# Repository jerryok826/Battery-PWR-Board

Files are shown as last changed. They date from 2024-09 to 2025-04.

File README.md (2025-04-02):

# Battery PWR Board

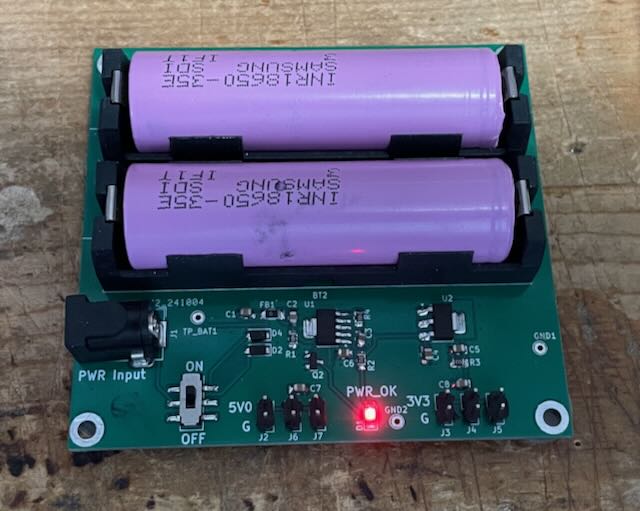
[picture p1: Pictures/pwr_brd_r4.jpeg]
Robot_Front


## Project Description
As systems and devices to test get smaller, large power supplies with their fans are often not required. The "Battery PWR Board" is a small board that can supply 5.0 amd/or 3.3 Volts. In a typical case two 18650 batteries may all that's required. The board can also run from a 9 volt battery or a wall wart. The on board PWR_OK LED is on when the 5.0 volt rail is within valid limits. Guaranting the batteries are ok. Since it can run from batteries and there is no active switching devices on board it is very low noise. 

### Project Status
The project is basically complete.

## Design Files
This project was designed with Kicad 7.X

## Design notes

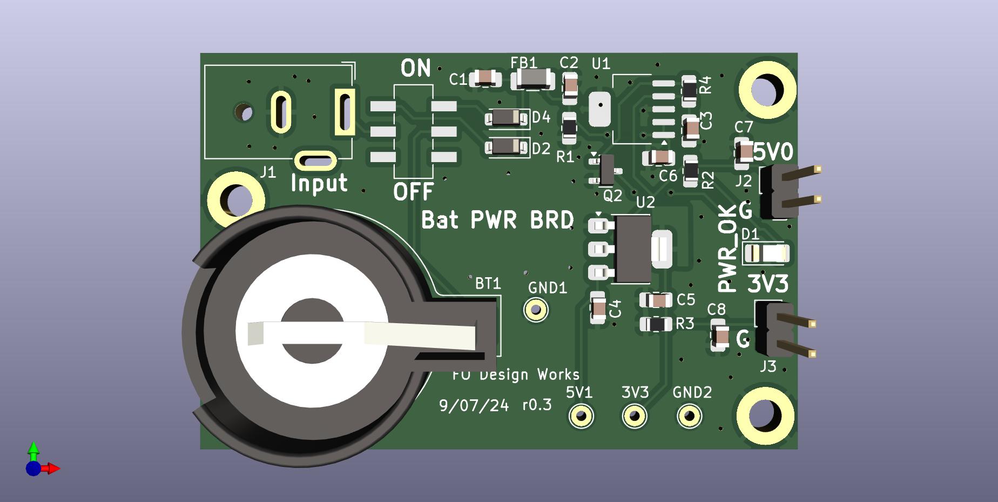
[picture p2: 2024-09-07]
Hardware/Kicad/battery_pwr_brd_r3.jpg

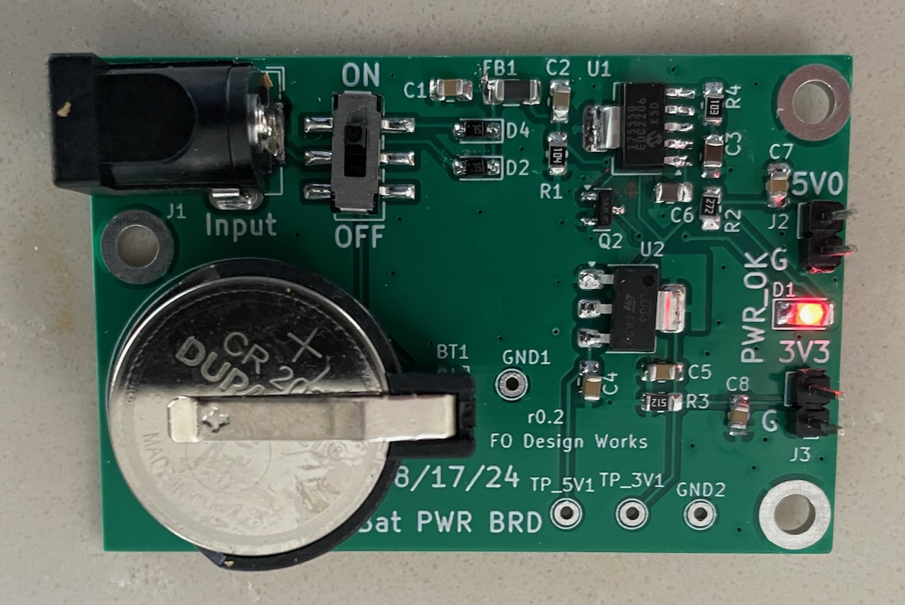
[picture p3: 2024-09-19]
Pictures/battery_pwr_brd_r3.jpeg

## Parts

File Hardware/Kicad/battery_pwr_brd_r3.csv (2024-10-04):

Source: | /home/jerryo/kicad/battery_pwr_brd/battery_pwr_brd_r3/battery_pwr_brd_r3.kicad_sch
Date: | Fri 04 Oct 2024 03:51:49 PM PDT
Tool: | Eeschema 7.0.11-7.0.11~ubuntu22.04.1
Generator: | /usr/share/kicad/plugins/bom_csv_grouped_by_value.py
Component Count: | 23
Collated Components:
Item | Qty | Reference(s) | Value | LibPart | Footprint | Datasheet | DNP | Description | Vendor | Vendor Part#
1 | 1 | BT1 | BATT HLD COIN 20MM 2 CELL PC PIN | Device:Battery | Battery:BatteryHolder_Keystone_103_1x20mm | ~ |  |  | Digikey | BH800S-ND
2 | 4 | C1, C2, C7, C8 | 0.1uF | Device:C_Small | Capacitor_SMD:C_0805_2012Metric_Pad1.18x1.45mm_HandSolder | ~ |  | CAP CER, 0.1uF, 25V, X7R, 0805 | Digikey | 1276-1099-1-ND
3 | 2 | C3, C6 | 4.7uF | Device:C_Small | Capacitor_SMD:C_0805_2012Metric_Pad1.18x1.45mm_HandSolder | ~ |  | CAP CER, 4.7uF, 25V, X7R, 0805 | Digikey | 1276-1244-1-ND
4 | 2 | C4, C5 | 1uF | Device:C_Small | Capacitor_SMD:C_0805_2012Metric_Pad1.18x1.45mm_HandSolder | ~ |  | CAP CER 1UF 25V X7R 0805 | Digikey | 1276-1066-1-ND
5 | 1 | D1 | PWR_OK | Device:LED | LED_SMD:LED_1206_3216Metric_Pad1.42x1.75mm_HandSolder | https://sunledusa.com/products/spec/XZM2CRK55W-3.pdf |  | LED RED CLEAR SMD 1206 | Digikey | 732-11422-1-ND
6 | 2 | D2, D4 | 1N5819W | Diode:1N5819WS | Diode_SMD:D_SOD-123 | https://datasheet.lcsc.com/lcsc/2204281430_Guangdong-Hottech-1N5819WS_C191023.pdf |  | DIODE SCHOTTKY 40V 1A SOD123FL | Digikey | 1655-1N5819WCT-ND
7 | 1 | FB1 | FerriteBead, 6A 1 9mΩ 33Ω@100MHz ±25% 1206 Ferrite Beads ROHS | Device:FerriteBead_Small | Inductor_SMD:L_1206_3216Metric_Pad1.42x1.75mm_HandSolder | https://www.fair-rite.com/wp-content/themes/fair-rite/print_product.php?pid=19229 |  | FERRITE BEAD 50 OHM 1206 1LN | Digikey | 1934-1465-1-ND
8 | 1 | J2 | Output_5V | Connector_Generic:Conn_01x02 |  | ~
9 | 1 | J3 | Output_3V3 | Connector_Generic:Conn_01x02 |  | ~
10 | 1 | Q2 | MMBT3904 | Transistor_BJT:MMBT3904 | Package_TO_SOT_SMD:SOT-23 | https://www.onsemi.com/pdf/datasheet/pzt3904-d.pdf |  | TRANS NPN 40V 0.2A SOT23-3 | Digikey | SMMBT3904LT3GOSCT-ND
11 | 1 | R1 | 100K | Device:R_Small_US | Resistor_SMD:R_0805_2012Metric_Pad1.20x1.40mm_HandSolder | ~ |  | RES 100K OHM %1 1/10W 0805 SMD | Digikey | 311-100KCRCT-ND
12 | 1 | R2 | 2.7K | Device:R_Small_US | Resistor_SMD:R_0805_2012Metric_Pad1.20x1.40mm_HandSolder | ~ |  | RES 2.7K OHM %1 1/10W 0805 SMD | Digiley | A126359CT-ND
13 | 1 | R3 | 5.1K | Device:R_Small_US | Resistor_SMD:R_0805_2012Metric_Pad1.20x1.40mm_HandSolder | ~ |  | RES 5.1K OHM %1 1/10W 0805 SMD | Digikey | 311-5.1KARCT-ND
14 | 1 | R4 | 10K | Device:R_Small_US | Resistor_SMD:R_0805_2012Metric_Pad1.20x1.40mm_HandSolder | ~ |  | RES 10K OHM %1 1/10W 1206 SMD | Digkey | 311-10.0KCRCT-ND
15 | 1 | SW1 | SW_DPDT_x2 | :SW_DPDT_x2_1 | jerrys_Library:SW_DPDT_CK_JS202011JCQN | https://www.ckswitches.com/media/1422/js.pdf |  | SWITCH SLIDE DPDT 300MA 6V | Digikey | 401-2002-1-ND
16 | 1 | U1 | MCP1755 | :MCP1755_1 | Package_TO_SOT_SMD:SOT-223-6 | https://ww1.microchip.com/downloads/en/DeviceDoc/MCP1755-MCP1755S-Data-Sheet-DS20005160B.pdf |  | IC REG LIN 3.3V 300MA SOT223-3 | Digikey | MCP1755ST-3302E/DBCT-ND
17 | 1 | U2 | LM1117MP-3.3 | Regulator_Linear:LM1117MP-3.3 | Package_TO_SOT_SMD:SOT-223-3_TabPin2 | http://www.ti.com/lit/ds/symlink/lm1117.pdf |  | IC REG LINEAR 3.3V 800MA SOT223 | Digikey | 497-1242-1-ND

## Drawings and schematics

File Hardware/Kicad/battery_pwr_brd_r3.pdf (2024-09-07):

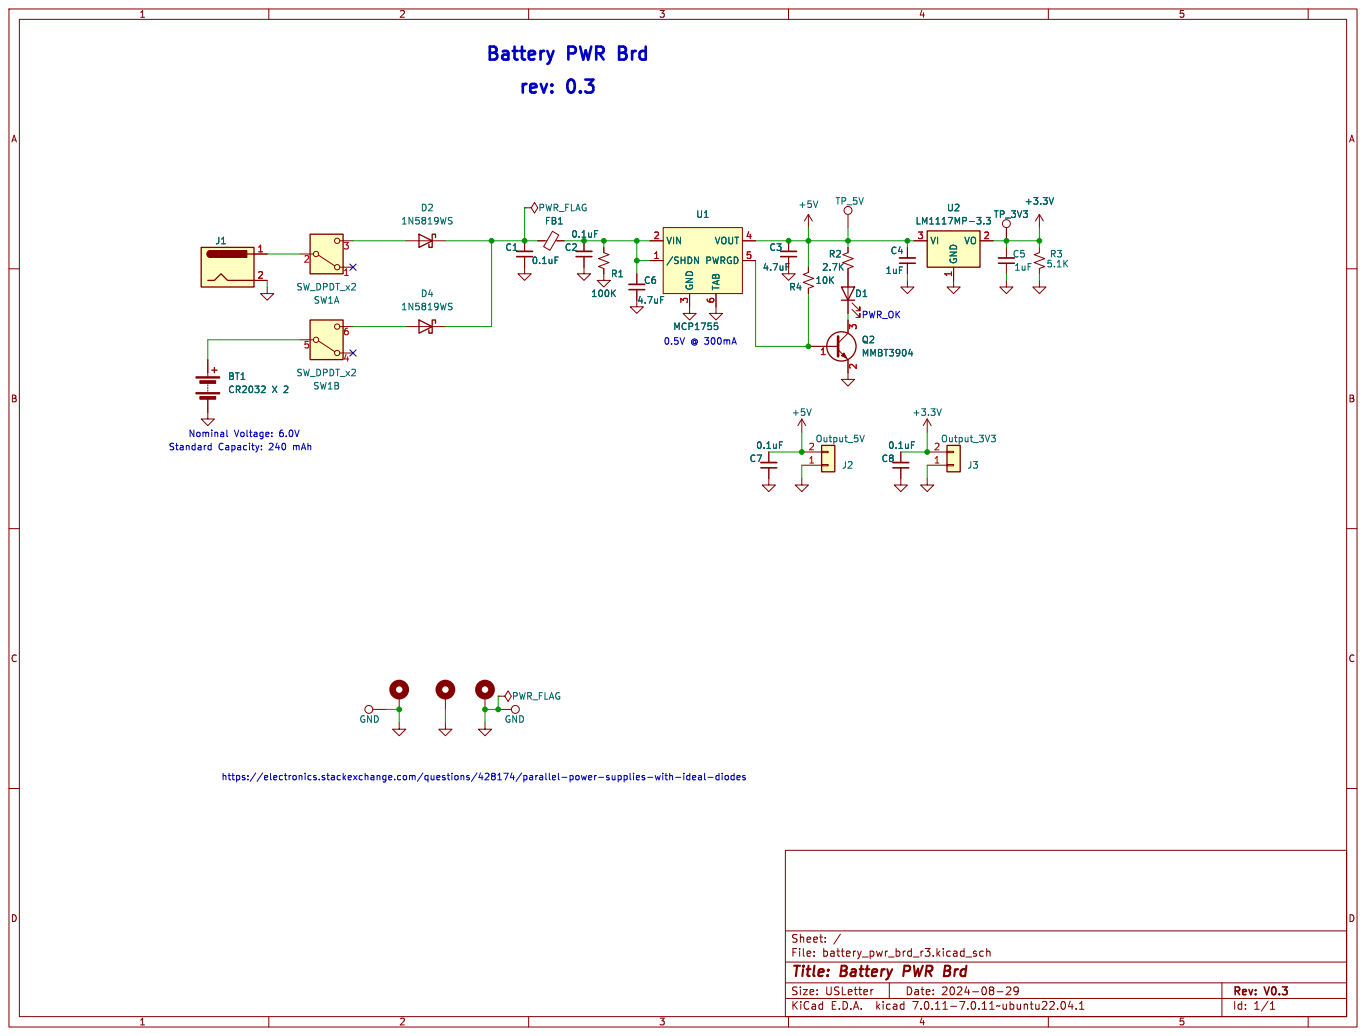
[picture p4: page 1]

https://electronics.stackexchange.com/questions/428174/parallel-power-supplies-with-ideal-diodes

File: battery_pwr_brd_r3.kicad_sch Sheet: /
Id: 1/1 Title: Battery PWR Brd

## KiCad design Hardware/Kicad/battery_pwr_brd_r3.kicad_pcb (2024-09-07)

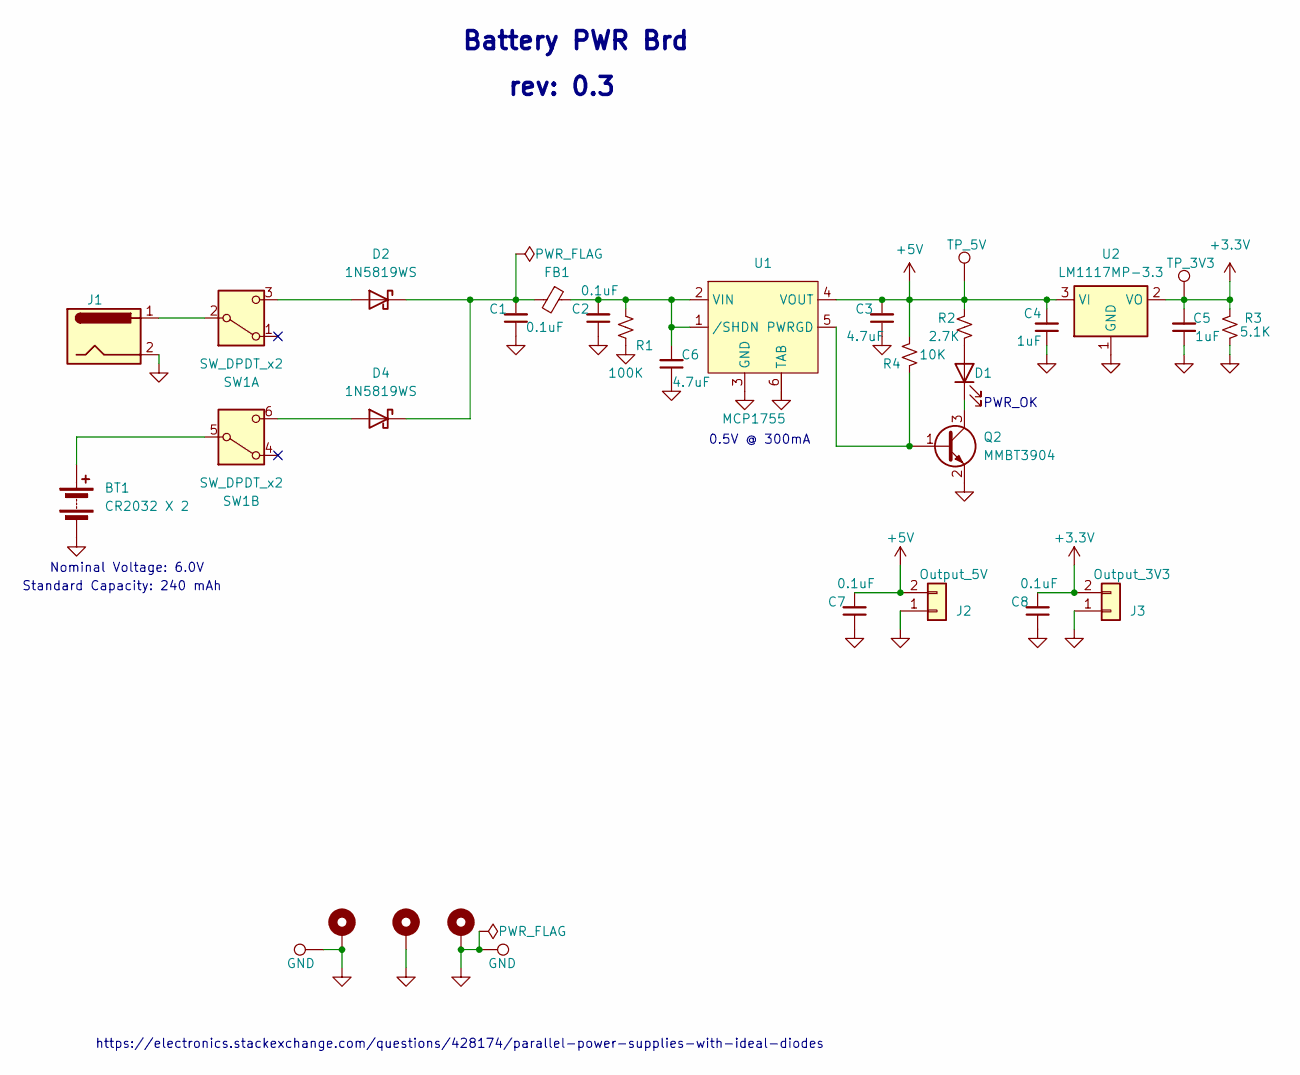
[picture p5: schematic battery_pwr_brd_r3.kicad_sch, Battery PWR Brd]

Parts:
BT1: CR2032 X 2; BatteryHolder_Keystone_103_1x20mm
C1, C2, C7, C8: 0.1uF; C_0805_2012Metric_Pad1.18x1.45mm_HandSolder
C3, C6: 4.7uF; C_0805_2012Metric_Pad1.18x1.45mm_HandSolder
C4, C5: 1uF; C_0805_2012Metric_Pad1.18x1.45mm_HandSolder
D1: OC_Fault; LED_1206_3216Metric_Pad1.42x1.75mm_HandSolder
D2, D4: 1N5819WS; D_SOD-123
FB1: FerriteBead, 6A 1 9mΩ 33Ω@100MHz ±25% 1206 Ferrit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; L_1206_3216Metric_Pad1.42x1.75mm_HandSolder
GND1, GND2: GND; TestPoint_THTPad_D2.0mm_Drill1.0mm
H1, H2, H3: MountingHole_Pad; MountingHole_3.2mm_M3_ISO7380_Pad_TopBottom
J1: INPUT_PWR; BarrelJack_GCT_DCJ200-10-A_Horizontal
J2: Output_5V
J3: Output_3V3
Q2: MMBT3904; SOT-23
R1: 100K; R_0805_2012Metric_Pad1.20x1.40mm_HandSolder
R2: 2.7K; R_0805_2012Metric_Pad1.20x1.40mm_HandSolder
R3: 5.1K; R_0805_2012Metric_Pad1.20x1.40mm_HandSolder
R4: 10K; R_0805_2012Metric_Pad1.20x1.40mm_HandSolder
SW1: SW_DPDT_x2; SW_DPDT_CK_JS202011JCQN
TP_3V1: TP_3V3; TestPoint_THTPad_D2.0mm_Drill1.0mm
TP_5V1: TP_5V; TestPoint_THTPad_D2.0mm_Drill1.0mm
U1: MCP1755; SOT-223-6
U2: LM1117MP-3.3; SOT-223-3_TabPin2

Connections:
+3.3V: C5.2, C8.2, J3.2, R3.2, TP_3V1.1, U2.2 (VO); also elsewhere on the board
+5V: C3.2, C4.2, C7.2, J2.2, R2.2, R4.2, TP_5V1.1, U1.4 (VOUT), U2.3 (VI); also elsewhere on the board
GND: BT1.2 (-), C1.1, C2.1, C3.1, C4.1, C5.1, C6.1, C7.1, C8.1, GND1.1, GND2.1, H1.1, H2.1, H3.1, J1.2, J2.1, J3.1, Q2.2 (E), R1.2, R3.1, U1.3 (GND), U1.6 (TAB), U2.1 (GND)
unnamed: BT1.1 (+), SW1.5 (B)
unnamed: D1.2 (A), R2.1
unnamed: D1.1 (K), Q2.3 (C)
unnamed: D2.2 (A), SW1.3 (C)
unnamed: C1.2, D2.1 (K), D4.1 (K), FB1.2
unnamed: D4.2 (A), SW1.6 (C)
unnamed: Q2.1 (B), R4.1, U1.5 (PWRGD)
unnamed: J1.1, SW1.2 (B)
unnamed: C2.2, C6.2, FB1.1, R1.1, U1.1 (/SHDN), U1.2 (VIN)

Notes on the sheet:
Standard Capacity: 240 mAh
rev: 0.3
0.5V @ 300mA
Battery PWR Brd
https://electronics.stackexchange.com/questions/428174/parallel-power-supplies-with-ideal-diodes
PWR_OK
Nominal Voltage: 6.0V

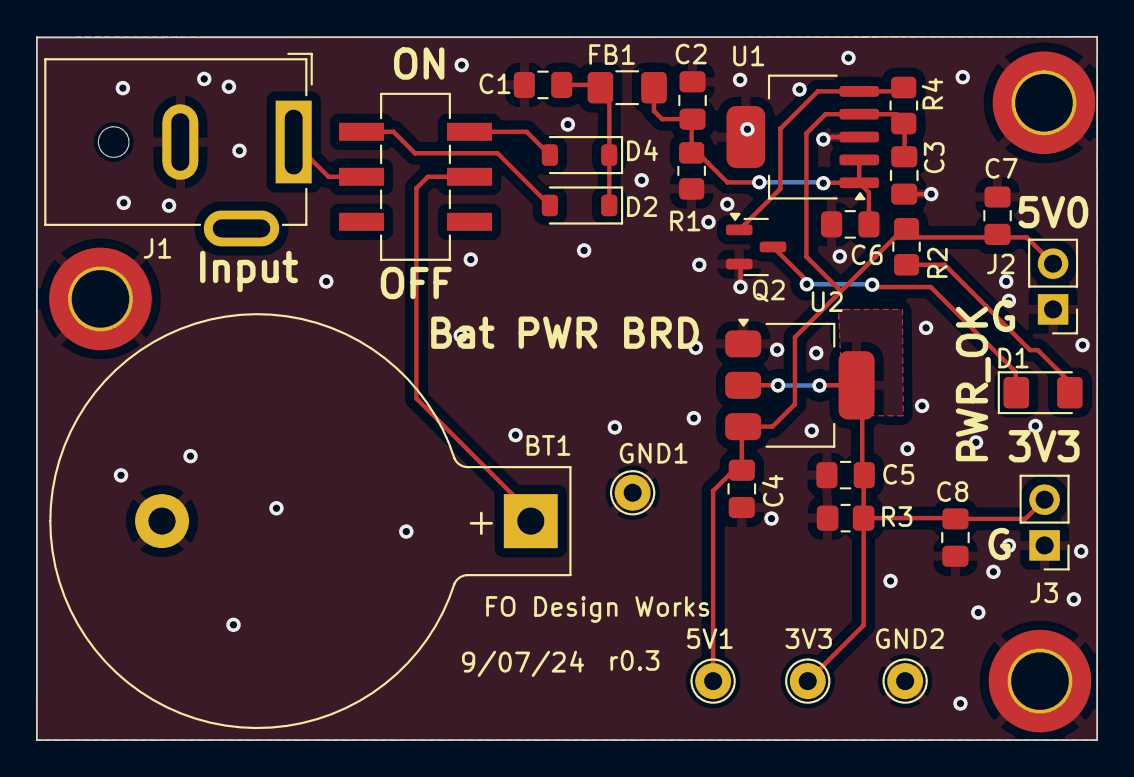
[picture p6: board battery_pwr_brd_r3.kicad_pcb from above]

Board: 2 copper layers, 58.9 x 39.1 mm, 31 parts (0 on the bottom side), 12 nets.

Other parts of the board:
3V3: TP_3V3; TestPoint_THTPad_D2.0mm_Drill1.0mm
5V1: TP_5V; TestPoint_THTPad_D2.0mm_Drill1.0mm

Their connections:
+3.3V: 3V3.1; also elsewhere on the board
+5V: 5V1.1; also elsewhere on the board
